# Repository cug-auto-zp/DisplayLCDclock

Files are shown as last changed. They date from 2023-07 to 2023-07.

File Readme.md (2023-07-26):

# Readme

[TOC]

## 0. 引言

之前一直想做一个辉光管时钟，由于成本太大，改为用LCD替换制作成类辉光管时钟，在github上看到了一个一模一样的项目废话不多说直接复刻

本项目为基于github上displayArray项目，其为一个开源的项目链接：[https://github.com/JosueAGtz/displayArray](https://github.com/JosueAGtz/displayArray)，项目作者使用的是==ESP32-S2==作为MCU，本人使用的是==合宙esp32-c3==，在复现的过程遇到了有几个问题之处。

- 遇到问题：
  
  - 图片显示都是反色。本人先买了==合宙esp32-c3（旧版）+LCD屏==测试了一下，这个LCD和项目使用的是一个屏幕都是ST7735s，一开始用转化好的图片.h库，显示是反色。本人重新取模发现这个屏幕是GBR排列，所以生成图片的时候得先反色再高位在前（为了方便本人已经将图片的.h重新更新了一下）
- 本人复刻过程
  - step1: 将==esp32-s2==代码转化可以烧录到合宙板子的代码，再用==合宙esp32-c3（旧版）+LCD屏==测试了一下程序，成功后就开始step2 设计PCB
  
    <video src="Readme-Fig/1.mp4"></video>
  
  - step2: 根据原理图重新设计并绘制PCB（ `主控` 和 `按键` 换了）
  
  - step3: 重新在别人的基础上更改及重新添加新功能
  
  - 注意：esp32-c3 的 GPIO11是需要解锁的，解锁前是一直给flash供电使用的，解锁后就可以当正常的GPIO使用。（在[Firmware](#3. Firmware)）

## SPI 屏幕——st7735

## 2. Hardware

主控：合宙esp32-c3开发版

官方手册链接：[ESP32C3-CORE开发板 - LuatOS 文档](https://wiki.luatos.com/chips/esp32c3/board.html)

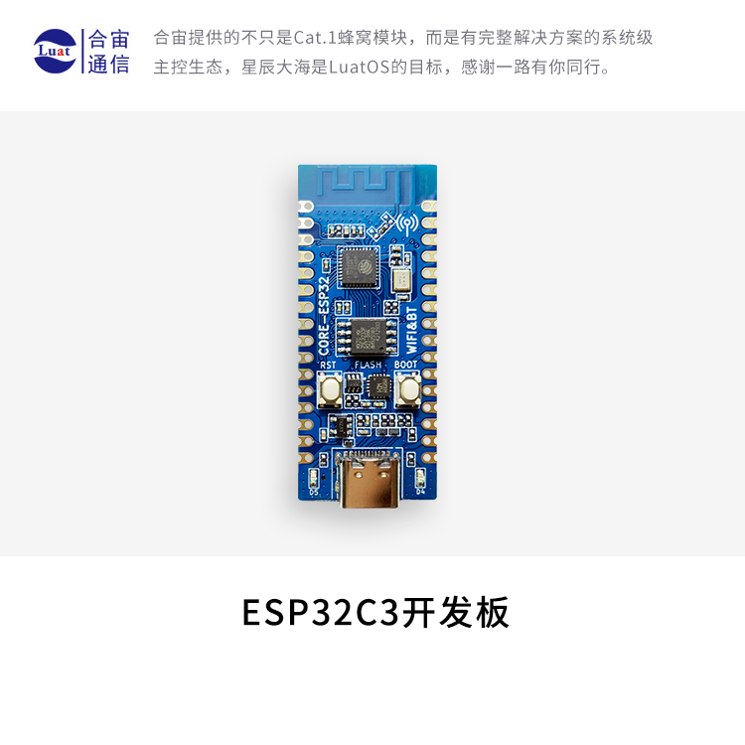
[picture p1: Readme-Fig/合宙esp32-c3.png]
合宙esp32-c3


其中使用AD20绘制了两个硬件

- displayLCD
- displaycontrl
- Hardware附件(材料来源等)

### 1. displayLCD

其中包含了6个SPI的TFT 80×160的屏幕的PCB，提供了5个按键可供多元创意开发

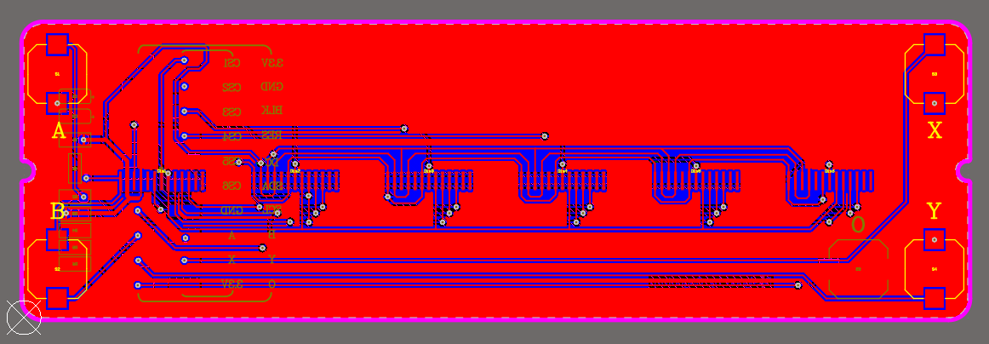
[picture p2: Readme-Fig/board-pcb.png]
board-pcb


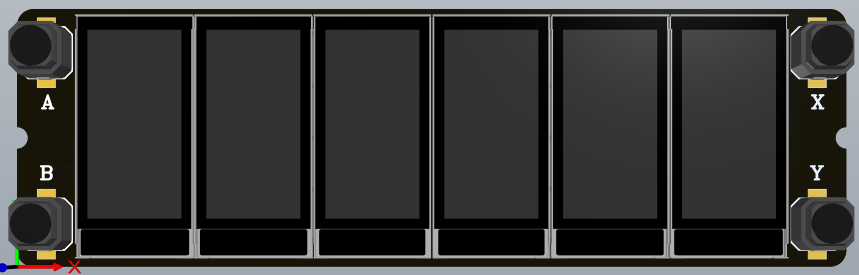
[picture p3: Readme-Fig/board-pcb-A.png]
board-pcb-A


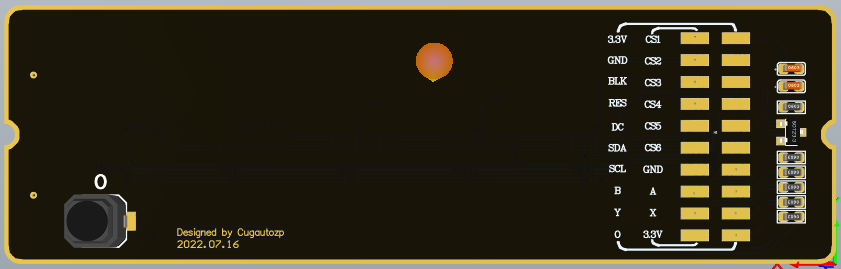
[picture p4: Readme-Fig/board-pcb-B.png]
board-pcb-B


实物如下：

### 2. displaycontrl

绘制了主控板，与合宙的esp32-c3开发板缝合。还留有 RX 和 TX 以供有人选取esp32-c3新版开发板下载程序问题。

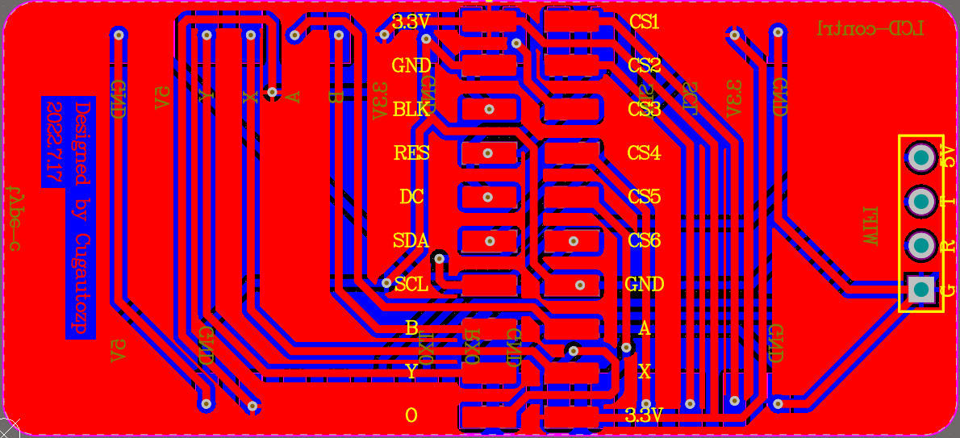
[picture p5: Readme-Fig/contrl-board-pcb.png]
contrl-board-pcb


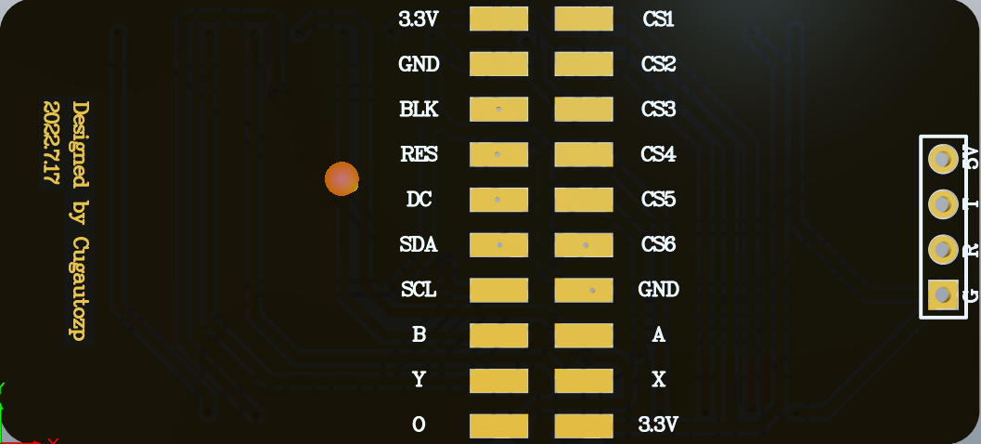
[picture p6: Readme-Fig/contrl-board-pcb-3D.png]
contrl-board-pcb-3D


实物图如下：

### 3. 硬件附件

| 材料 | 名称 | 购买链接 |
| :---: | :---: | :---: |
| TFT0.96”的屏幕 | st7735s (80×160) | |
| 开发板 | 合宙esp32-c3（旧版）价格：12.9，（新版）价格：9.9 | |
| 按键 | 6\*6*5贴片无声硅胶按键 | |
| 排针 | 卧式贴片排针公/母 | |

## 3. Firmware

采用编译环境是：Vscode + platformIO + Arduino框架

### 1. 安装教程

- Vscode 官方下载链接：[Visual Studio Code](https://code.visualstudio.com/)
- 看这位（up 主：Homepea）视频：[Vscode + platformIO + Arduino安装及配置环境教学视频](https://www.bilibili.com/video/BV1tv411w74d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)

### 2. 代码解释

- 代码在文件：`Firmware/code`
- 配置好环境后，打开工程文件`code`，编译一下主函数`main.cpp`
- 代码注意事项及部分解释在 [Code Readme](./Firmware/Readme.md) 

### 3. 图片取模Tool

- 为了增加diy可玩性，提供取模工具在文件`Tool`，以供大家选取自己喜欢的图片
- 如果图片是`.png`格式建议转化为`.jpg`格式

### 4. 二维码生成

- 二维的生成是用来配置esp32-c3的WiFi，让它连接想要连接的WiFi热点，比直接写在代码中会比较灵活一些

- Wifi 配置使用二维码扫描连接ESP32C3的热点(热点名及密码由 user_config.h 中 AP_SSID和AP_PASSWORD 配置), 同步需要修改二维码图片 (WifiQrcode.h): 

  ```txt
  WIFI:T:WPA;S:热点名;P:密码;
  
  例如：WIFI:T:WPA;S:esp32-c3;P:;
  ```

  到草料网：[草料二维码生成器 ](https://cli.im/) ，（可以更具自己的喜好更改样式）

  把上面的例子复制

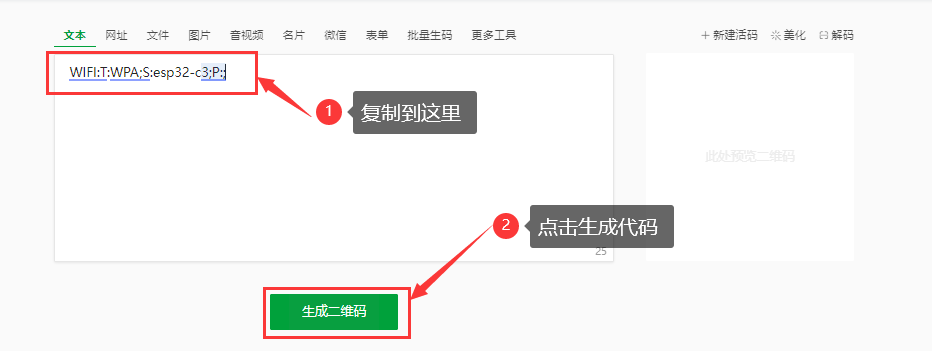
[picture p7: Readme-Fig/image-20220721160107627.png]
  

  点击这个设置，设置到 `80px`，改完后直接下载

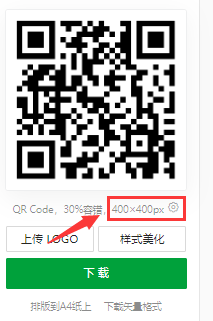
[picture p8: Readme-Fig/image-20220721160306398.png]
  

  > 在编写的过程中遇到了一些问题，询问了一位大佬，非常感谢这位大佬的答疑解惑，Github: [Kerrbty/ESP32C3Clock: 太空人时钟，基于ESP32-C3芯片](https://github.com/Kerrbty/ESP32C3Clock)

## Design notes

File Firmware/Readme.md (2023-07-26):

# Readme

## Code

### 1. 引脚配置

主控引脚定义：

引脚定义

上图预留给出了GPIO 0~13 和 18~19，下面进行本项目的功能复用，使用了一根SPI总线

`注意：`其中 GPIO 11 原来是给flash供电使用，所以需要解锁才能作为正常的 GPIO 使用，flash可以使用外部供电，不用担心解锁后存在的问题。解锁教程链接：[GPIO 11 解锁](https://gitee.com/dreamcmi/LuatOS-ESP32/blob/master/doc/VDD_SPI_AS_GPIO.md)

|  GPIO |  功能复用 | 说明 |
| :-----: | :---: | :---: |
| GPIO 0  | CS1 | 控制第一块LCD |
| GPIO 1  | CS2 | 控制第二块LCD |
| GPIO 2  | SCL（SCK）  | SPI的时钟 |
| GPIO 3  | MOSI（SDA） | |
| GPIO 4  | A | PCB-按键 A |
| GPIO 5  | B | PCB-按键 B |
| GPIO 6  | DC | |
| GPIO 7  | CS3 | 控制第三块LCD |
| GPIO 8  | X | PCB-按键 X |
| GPIO 9  | Y | PCB-按键 Y |
| GPIO 10 | RES | res复位 |
| GPIO 11 | BLK | 屏幕背光解锁后可以使用PWM调节背光 |
| GPIO 12 | CS4 | 控制第四块LCD |
| GPIO 13 | CS5 | 控制第五块LCD |
| GPIO 18 | CS6 | 控制第六块LCD |
| GPIO 19 | O | PCB-按键 O |
| | | |

### 2. code-v1.0

由于：Hardware 中 contrl-v1.0 板子有点小失误 GPIO18 控制第5块 LCD，GPIO13 控制第6块 LCD

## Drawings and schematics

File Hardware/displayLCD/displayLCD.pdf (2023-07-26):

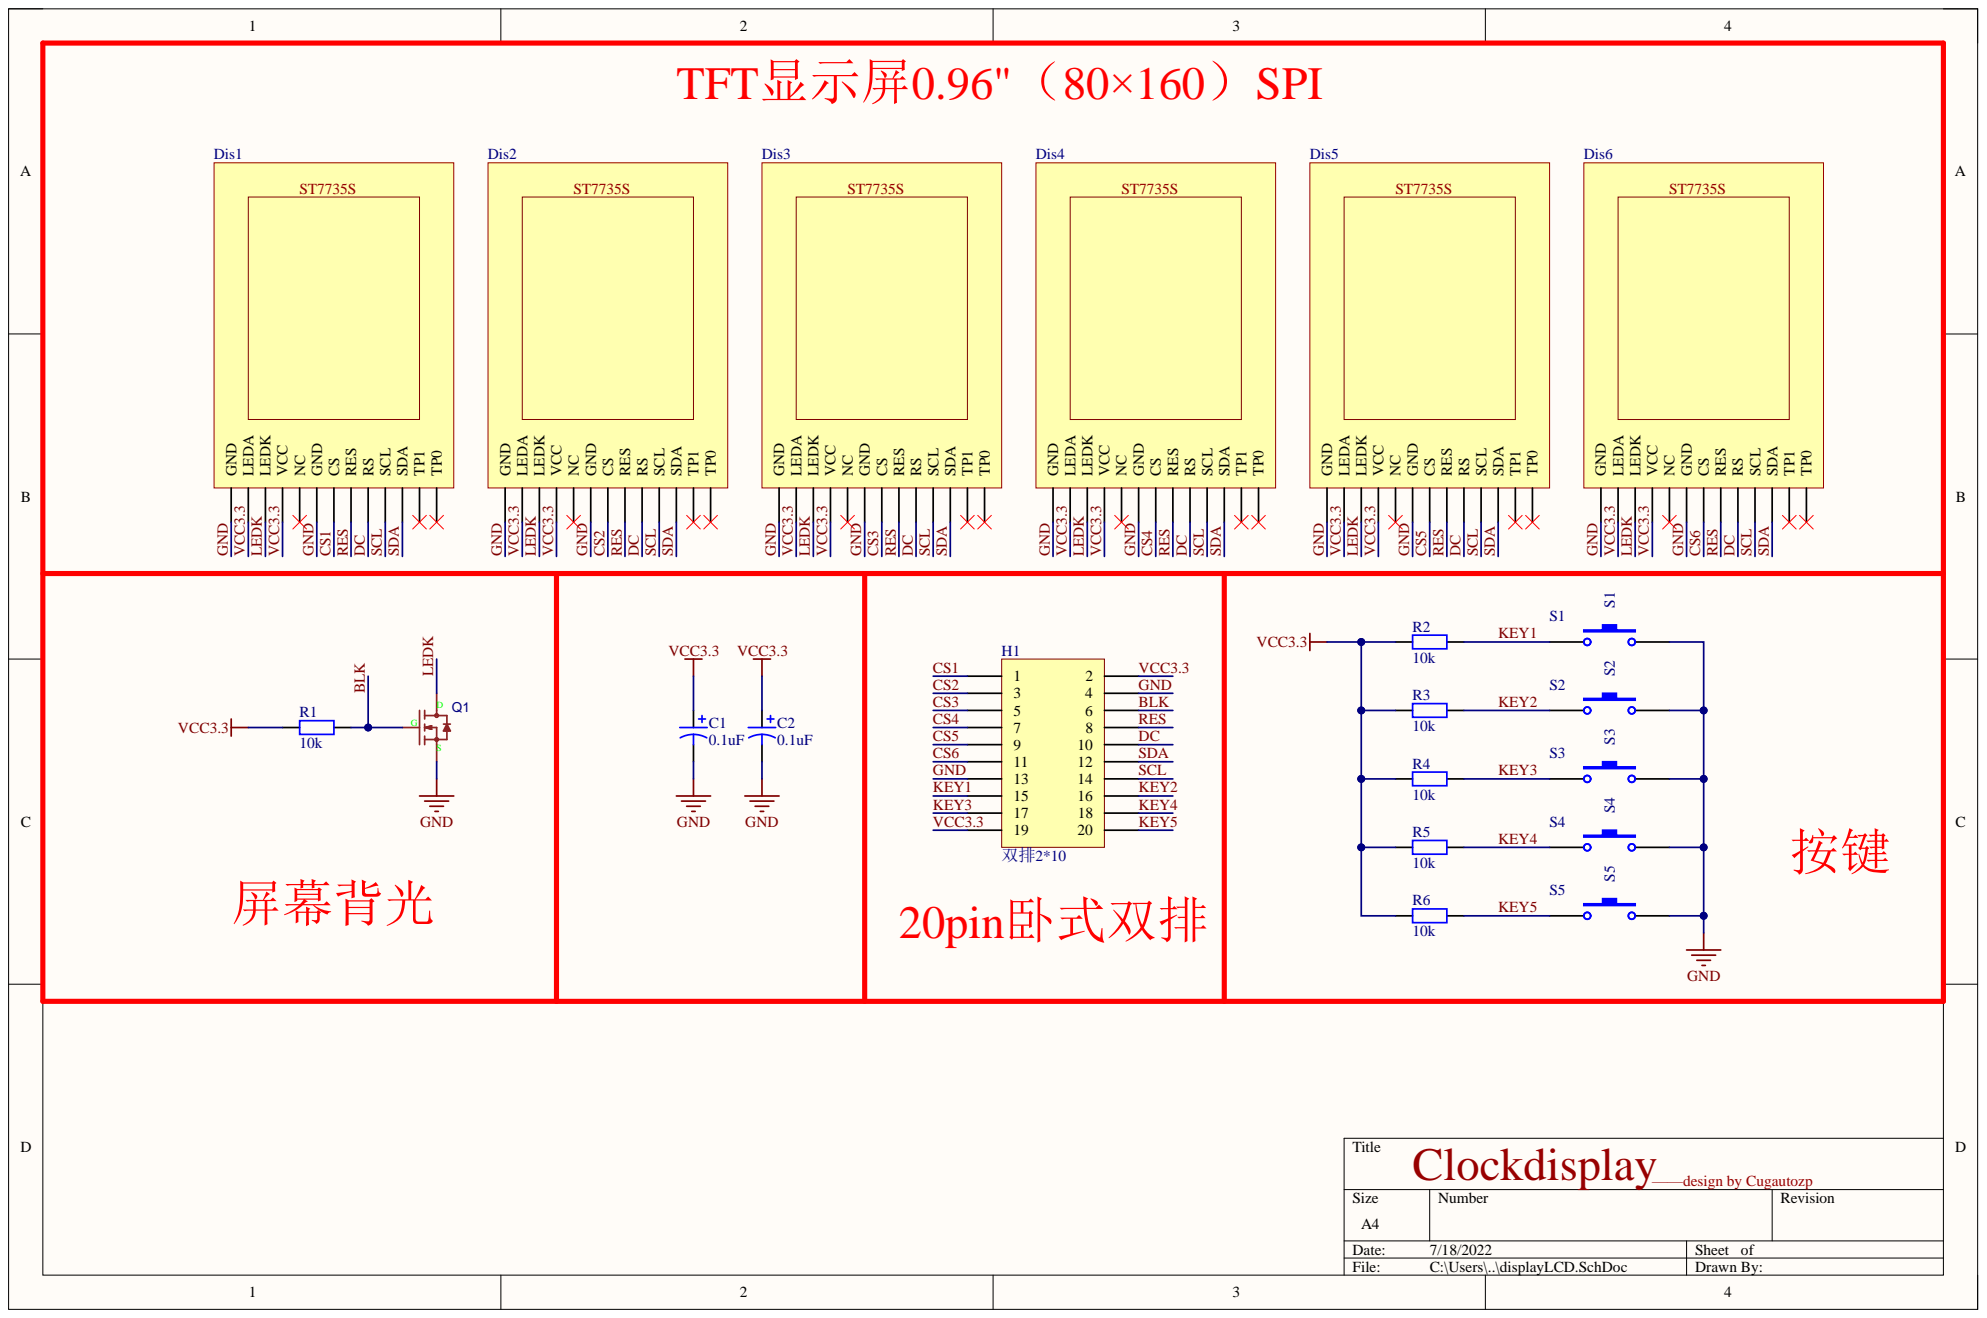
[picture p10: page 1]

Clockdisplay——design by Cugautozp

Item # | Designator | Description | Comment | Quantity #Column Name Error:' Manuf#Cacolture um n Name Error:' Manufacturer Part Num | Footprint | LibRef | #Column Name Error:' Note
1 | C1, C2 | Polarized Capacitor (Surface Mount) | 0.1uF | 2 | Cap0603 | Cap Pol3
2 | Dis1, Dis2, Dis3, Dis4, Dis5, Dis6 | | LCD80*160 | 6 | LCD屏80*160 | LCD80*160
3 | H1 | | 双排2*10 | 1 | pin20双排母 | 双排2*10
4 | Q1 | | LN4812LT1G | 1 | sot23 | LN4812LT1G
5 | R1, R2, R3, R4, R5, R6 | Resistor | 10k | 6 | R0603 | Res2
6 | S1 | Switch | S1 | 1 | key(按键) | SW-PB
7 | S2 | Switch | S2 | 1 | key(按键) | SW-PB
8 | S3 | Switch | S3 | 1 | key(按键) | SW-PB
9 | S4 | Switch | S4 | 1 | key(按键) | SW-PB
10 | S5 | Switch | S5 | 1 | key(按键) | SW-PB

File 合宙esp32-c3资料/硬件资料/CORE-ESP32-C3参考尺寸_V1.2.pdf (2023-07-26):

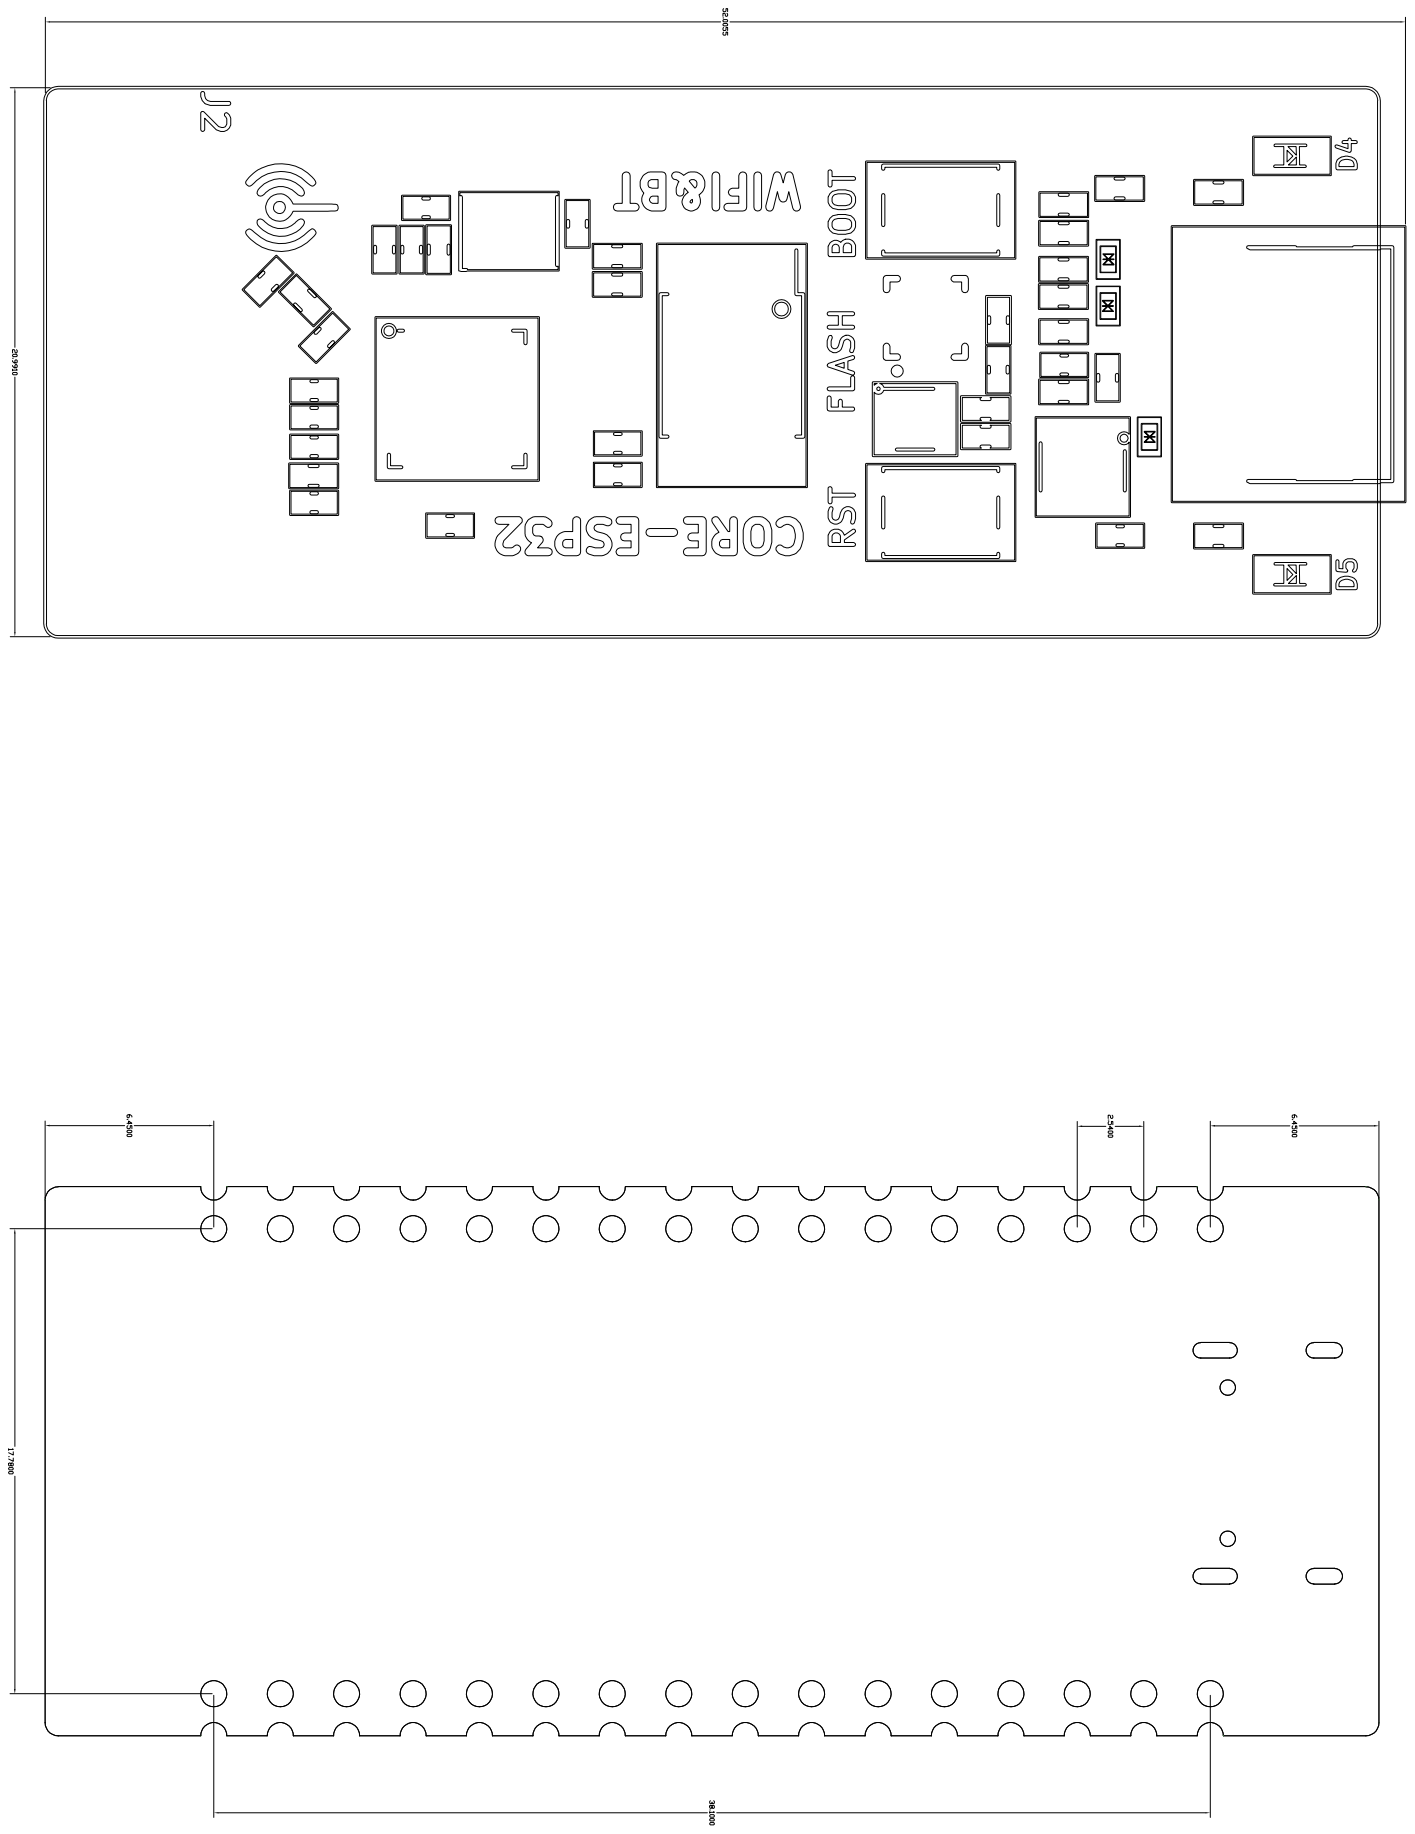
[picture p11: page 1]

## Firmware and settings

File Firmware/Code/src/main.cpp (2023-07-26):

#include "WiFiUser.h"     //  连接wifi热点选择配置网络
#include "displaystyle.h" //  展示样式

// //填写WIFI入网信息
// const char *ssid = "zp-laptop";     // WIFI账户
// const char *password = "cugautozp"; // WIFI密码

#define NTP1 "ntp1.aliyun.com"
#define NTP2 "ntp2.aliyun.com"
#define NTP3 "ntp3.aliyun.com"

// WiFiUDP ntpUDP;
// NTPClient timeClient(ntpUDP,"ntp.ntsc.ac.cn");

#define Key0 4  //  A
#define Key1 5  //  B
#define Key2 8  // x
#define Key3 9  // y
#define Key4 19 // o 暂时没有使用

// ST7735 width height
#define DISPLAY_WIDTH 160
#define DISPLAY_HEIGHT 80

int64_t stylenum = 1;
int64_t stylenum1 = 1;

uint8_t secondsCounter = 0;
uint8_t secondsStatus = 0;
uint8_t prevHours, prevMinutes;
struct tm timeinfo;

uint8_t b = 0;

int64_t blkpwm = 512; // 背光初始状态
int64_t blkpwm1 = 0;  // 保存当前背光状态
int64_t blkpwm2 = 0;  // 附状态机状态
int64_t keyFlag = 0;  // 按键状态
int64_t keyFlag1 = 0; // 按键状态

void setClock()
{
  if (!getLocalTime(&timeinfo))
  { //如果获取失败，就开启联网模式，获取时间
    Serial.println("Failed to obtain time");

    /*
       WIFI 直接连接
    */
    // WiFi.disconnect(false);
    // WiFi.mode(WIFI_STA); //开启网络
    // WiFi.begin(ssid, password);
    // while (WiFi.status() != WL_CONNECTED)
    // {
    //   delay(500);
    //   Serial.print(".");
    // }

    // 读取之前的wifi配置
    if (!ReadWifiConfig())
    {
      ConfigWifi();
    }

    // 连接wifi
    while (!ConnectWifi())
    {
      ConfigWifi();
    }
    spilcdWriteString(&lcd[5], 0, 0, (char *)"WIFI ok!", 0xffff, 0x0000, FONT_8x8, DRAW_TO_LCD);

    configTime(8 * 3600, 0, NTP1, NTP2, NTP3);
    return;
  }
  // Serial.println(&timeinfo, "%F %T %A"); // 格式化输出:2021-10-24 23:00:44 Sunday
  // Serial.println(timeinfo.tm_hour);
  WiFi.disconnect(true);
}

void LCD_init()
{

  ledcWrite(1, 0);
  pinMode(RESET_PIN, OUTPUT);
  digitalWrite(RESET_PIN, HIGH);
  digitalWrite(RESET_PIN, LOW);
  delay(50);
  digitalWrite(RESET_PIN, HIGH);

  for (int i = 0; i < 6; i++)
  {
    spilcdInit(&lcd[i], LCD_ST7735S_B, FLAGS_INVERT | FLAGS_SWAP_RB, 40000000, cs[i], DC_PIN, -1, -1, MISO_PIN, MOSI_PIN, SCK_PIN);
    spilcdSetOrientation(&lcd[i], LCD_ORIENTATION_180);
    lcdDrawNumber(i, 11, stylenum);
  }
  ledcWrite(1, blkpwm);
}

// void wifi_init()
// {
//   uint8_t wifiConectionAttmps = 0;
//   WiFi.mode(WIFI_STA); // wifi 连接模式
//   WiFi.begin(ssid, password);

//   Serial.print("Connecting to ");
//   Serial.print(ssid);
//   while (WiFi.status() != WL_CONNECTED & wifiConectionAttmps < 20)
//   {
//     delay(500);
//     Serial.print(".");
//     wifiConectionAttmps++;
//   }

//   if (WiFi.status() == WL_CONNECTED)
//   {
//     Serial.println("OK. WiFi connected!");
//   }
//   else
//   {
//     Serial.println("ERROR.");
//     Serial.println("Connection Failed!, please check credentials and try again.");
//   }
// }

void gethour(uint8_t stylenum)
{
  if (timeinfo.tm_hour != prevHours | stylenum1 != stylenum)
  {
    prevHours = timeinfo.tm_hour;
    // Serial.println(timeinfo.tm_hour);
    if (timeinfo.tm_hour < 10)
    {
      lcdDrawNumber(0, 0, stylenum);
      lcdDrawNumber(1, timeinfo.tm_hour, stylenum);
    }
    else if (timeinfo.tm_hour < 20)
    {
      lcdDrawNumber(0, 1, stylenum);
      lcdDrawNumber(1, timeinfo.tm_hour - 10, stylenum);
    }
    else
    {
      lcdDrawNumber(0, 2, stylenum);
      lcdDrawNumber(1, timeinfo.tm_hour - 20, stylenum);
    }
  }
}

void getmin(uint8_t stylenum)
{
  if (timeinfo.tm_min != prevMinutes | stylenum1 != stylenum)
  {
    prevMinutes = timeinfo.tm_min;
    // Serial.println(timeinfo.tm_min);
    if (timeinfo.tm_min < 10)
    {
      lcdDrawNumber(3, 0, stylenum);
      lcdDrawNumber(4, timeinfo.tm_min, stylenum);
    }
    else if (timeinfo.tm_min < 20)
    {
      lcdDrawNumber(3, 1, stylenum);
      lcdDrawNumber(4, timeinfo.tm_min - 10, stylenum);
    }
    else if (timeinfo.tm_min < 30)
    {
      lcdDrawNumber(3, 2, stylenum);
      lcdDrawNumber(4, timeinfo.tm_min - 20, stylenum);
    }
    else if (timeinfo.tm_min < 40)
    {
      lcdDrawNumber(3, 3, stylenum);
      lcdDrawNumber(4, timeinfo.tm_min - 30, stylenum);
    }
    else if (timeinfo.tm_min < 50)
    {
      lcdDrawNumber(3, 4, stylenum);
      lcdDrawNumber(4, timeinfo.tm_min - 40, stylenum);
    }
    else
    {
      lcdDrawNumber(3, 5, stylenum);
      lcdDrawNumber(4, timeinfo.tm_min - 50, stylenum);
    }
  }
}

void getmin1(uint8_t stylenum)
{
  if (timeinfo.tm_min != prevMinutes | stylenum1 != stylenum)
  {
    prevMinutes = timeinfo.tm_min;
    // Serial.println(timeinfo.tm_min);
    if (timeinfo.tm_min < 10)
    {
      lcdDrawNumber(2, 0, stylenum);
      lcdDrawNumber(3, timeinfo.tm_min, stylenum);
    }
    else if (timeinfo.tm_min < 20)
    {
      lcdDrawNumber(2, 1, stylenum);
      lcdDrawNumber(3, timeinfo.tm_min - 10, stylenum);
    }
    else if (timeinfo.tm_min < 30)
    {
      lcdDrawNumber(2, 2, stylenum);
      lcdDrawNumber(3, timeinfo.tm_min - 20, stylenum);
    }
    else if (timeinfo.tm_min < 40)
    {
      lcdDrawNumber(2, 3, stylenum);
      lcdDrawNumber(3, timeinfo.tm_min - 30, stylenum);
    }
    else if (timeinfo.tm_min < 50)
    {
      lcdDrawNumber(2, 4, stylenum);
      lcdDrawNumber(3, timeinfo.tm_min - 40, stylenum);
    }
    else
    {
      lcdDrawNumber(2, 5, stylenum);
      lcdDrawNumber(3, timeinfo.tm_min - 50, stylenum);
    }
  }
}

void getsec(uint8_t stylenum)
{
  if (timeinfo.tm_sec != prevMinutes | stylenum1 != stylenum)
  {
    prevMinutes = timeinfo.tm_sec;
    Serial.println(timeinfo.tm_sec);
    if (timeinfo.tm_sec < 10)
    {
      lcdDrawNumber(4, 0, stylenum);
      lcdDrawNumber(5, timeinfo.tm_sec, stylenum);
    }
    else if (timeinfo.tm_sec < 20)
    {
      lcdDrawNumber(4, 1, stylenum);
      lcdDrawNumber(5, timeinfo.tm_sec - 10, stylenum);
    }
    else if (timeinfo.tm_sec < 30)
    {
      lcdDrawNumber(4, 2, stylenum);
      lcdDrawNumber(5, timeinfo.tm_sec - 20, stylenum);
    }
    else if (timeinfo.tm_sec < 40)
    {
      lcdDrawNumber(4, 3, stylenum);
      lcdDrawNumber(5, timeinfo.tm_sec - 30, stylenum);
    }
    else if (timeinfo.tm_sec < 50)
    {
      lcdDrawNumber(4, 4, stylenum);
      lcdDrawNumber(5, timeinfo.tm_sec - 40, stylenum);
    }
    else
    {
      lcdDrawNumber(4, 5, stylenum);
      lcdDrawNumber(5, timeinfo.tm_sec - 50, stylenum);
    }
  }
}

void clkcolon(uint8_t stylenum )
{

  // if 
 
  if ((stylenum1 != stylenum) | (secondsCounter > 25 & secondsStatus == 0) )
  {
    lcdDrawNumber(2, 10, stylenum);
    // lcdDrawNumber(6,10);
    secondsStatus = 1;
    secondsCounter = 0;
  }
  else if (  (secondsCounter > 25 & secondsStatus == 1) | (stylenum1 != stylenum))
  {
    lcdDrawNumber(2, 11, stylenum);
    // lcdDrawNumber(6,11);
    secondsStatus = 0;
    secondsCounter = 0;
  }

  delay(20);
  secondsCounter++;

  // if (stylenum1 != stylenum)
  // {
  //   secondsCounter = 0;
  //   secondsStatus = 0;
  // }


}

// void KeyScan()
// {

//   if (keyFlag == 1)
//   {
//     // 检查按键是否释放
//     if (digitalRead(Key0) == 0)
//       return;
//     else if (digitalRead(Key1) == 0)
//       return;
//     else if (digitalRead(Key2) == 0)
//       return;
//     else if (digitalRead(Key3) == 0)
//       return;
//     else if (digitalRead(Key4) == 0)
//       return;
//     else
//       keyFlag = 0; //按键已经释放
//   }

//   else
//   {
//     if (digitalRead(Key0) == 0)
//     {
//       keyFlag = 1;
//       stateFlag = stateFlag + 20;
//       if (stateFlag > 1024)
//         stateFlag = 0;
//       return;
//     }
//     else if (digitalRead(Key1) == 0)
//     {
//       keyFlag = 1;
//       if (stateFlag > 0)
//         stateFlag = stateFlag - 20;
//       else
//         stateFlag = 1024;
//       return;
//     }
//     else if (digitalRead(Key2) == 0)
//     {
//       keyFlag = 1;
//       if (b == 0)
//         b = 1;
//       else
//         b = 0;

//       return;
//     }
//     else if (digitalRead(Key3) == 0)
//     {
//       keyFlag = 1;

//       stateFlag2 = stateFlag2 + 1;
//       if (stateFlag2 > 2)
//         stateFlag2 = 0;
//       return;
//     }
//     else if (digitalRead(Key4) == 0)
//     {
//       keyFlag = 1;

//       if (stateFlag > 0)
//       {
//         a = stateFlag;
//         stateFlag = 0;
//       }
//       else
//         stateFlag = a;
//       return;

//       if (stateFlag > 0)
//       {
//         a = stateFlag;
//         stateFlag = 0;
//       }
//       else
//         stateFlag = a;
//       return;
//     }
//   }
// }

void KeyScan()
{

  if (keyFlag == 0)
  {
    // 检查按键是否释放
    if (digitalRead(Key0) == 0)
    {

      spilcdWriteString(&lcd[5], 0, 40, (char *)"Seting", 0xffff, 0x0000, FONT_8x8, DRAW_TO_LCD);
      keyFlag = 1;
      return;
    }
    else if (digitalRead(Key1) == 0)
      return;
    else if (digitalRead(Key2) == 0)
      return;
    else if (digitalRead(Key3) == 0)
      return;
    else if (digitalRead(Key4) == 0)
      return;
    else
      keyFlag = 0; //按键已经释放
  }
  else if (keyFlag == 1)
  {
    if (keyFlag1 == 1)
    {
      if (digitalRead(Key0) == 0)
        return;
      else if (digitalRead(Key1) == 0)
        return;
      else if (digitalRead(Key2) == 0)
        return;
      else if (digitalRead(Key3) == 0)
        return;
      else if (digitalRead(Key4) == 0)
        return;
      else
        keyFlag1 = 0; //按键已经释放
    }
    else if (keyFlag1 == 0)
    {
      if (digitalRead(Key0) == 0)
      {
        keyFlag1 = 1;
        blkpwm = blkpwm + 20;
        if (blkpwm > 1024)
          blkpwm = 0;
        return;
      }
      else if (digitalRead(Key1) == 0)
      {
        keyFlag1 = 1;
        if (blkpwm > 0)
          blkpwm = blkpwm - 20;
        else
          blkpwm = 1024;
        return;
      }
      else if (digitalRead(Key2) == 0)
      {
        keyFlag1 = 1; 
        stylenum1 =stylenum;
        stylenum = stylenum + 1;
        
        if (stylenum > 8) 
          stylenum = 0;
        return;
      }
      else if (digitalRead(Key3) == 0)
      {
        keyFlag1 = 1;
        stylenum1 =stylenum;
        stylenum = stylenum - 1;
        if (stylenum < 0)       
          stylenum = 8;
        return;
      }
      else if (digitalRead(Key4) == 0)
      {
        keyFlag1 = 1;

        if (blkpwm > 0)
        {
          blkpwm1 = blkpwm;
          blkpwm = 0;
        }
        else
          blkpwm = blkpwm1;
        return;
      }
    }
  }
}

void setup()
{
  Serial.begin(115200);
  while (!Serial)
    ;
  pinMode(11, OUTPUT);
  ledcSetup(1, 1000, 10);
  ledcAttachPin(11, 1);
  ledcWrite(1, blkpwm);

  pinMode(Key0, INPUT_PULLUP);
  pinMode(Key1, INPUT_PULLUP);
  pinMode(Key2, INPUT_PULLUP);
  pinMode(Key3, INPUT_PULLUP);
  pinMode(Key4, INPUT_PULLUP);

  LCD_init(); // 屏幕初始化

  // lcdDrawFlag(5, 3); //

  // wifi_init();                               // wifi初始化
  configTime(8 * 3600, 0, NTP1, NTP2, NTP3); // 时区设定 北京时间为 GTM +8
  setClock();
  // 读取之前的wifi配置
    if ( !ReadWifiConfig() )
    {
        ConfigWifi();
    }

    // 连接wifi
    while( !ConnectWifi() )
    {
        ConfigWifi();
    }

  WiFi.disconnect(true);
  WiFi.mode(WIFI_OFF); //关闭网络

  // Serial.println("WiFi disconnected!");
  // timeClient.begin();
  // timeClient.setTimeOffset(8*3600);     // 时区设定 北京时间为 GTM +8
  // timeClient.update();

  prevHours = 60;
  prevMinutes = 60;
}

void loop()
{

  Serial.println(stylenum);
  // Serial.println("up: ");
  KeyScan();
  ledcWrite(1, blkpwm);
  // Serial.print(blkpwm);
  setClock();

  switch (b)
  {
  case 0:
    gethour(stylenum);
    getmin(stylenum);
    clkcolon(stylenum);
    lcdDrawNumber(5, 12, stylenum);
    stylenum1 = stylenum;
    Serial.println(stylenum1);
    break;

  case 1:
    gethour(stylenum);

    // getmin();

    getmin1(stylenum);
    //
    getsec(stylenum);
    break;
  }
}

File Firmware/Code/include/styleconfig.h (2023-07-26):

#ifndef __STYLECONFIG_H__
#define __STYLECONFIG_H__

// #include "clock14SEG.h"
#include "clockBINA.h"
#include "clockButterfly.h"
#include "clockDigital.h"
#include "clockFlip.h"
#include "clockFlower.h"
#include "clockInk.h"
#include "clockLixieCyan.h"
#include "clockLixiePurple.h"
#include "clockMatrix.h"
// #include "clockNIMO.h"
#include "clockNixie.h"
#include "clockPixie.h"
#include "clockPredator.h"
#include "clockRGB.h"
#include "clockStargate.h"
#include "clockVFD.h"
// #include "clockWood.h"
// #include "clockFlags.h"

/*   屏幕引脚配置   */

#define CS1_PIN 0  // 1
#define CS2_PIN 1  // 18 //2
#define CS3_PIN 7  // 13//5 //3
#define CS4_PIN 12 // 4
#define CS5_PIN 18 // 19
#define CS6_PIN 13 // 7 //6

#define RESET_PIN 10    //    res
#define DC_PIN    6     //    DC
#define MOSI_PIN  3     //    SDA
#define SCK_PIN   2     //    SCL
#define LED_PIN   11    //    BLK   LCD背光
#define MISO_PIN -1     //    引脚为空


#define colon  10
#define space  11
#define heart  12
    



/*   style切换   */
// #define SEG14           0
#define BINA            0 // 1 
#define Butterfly       1 // 2
// #define Digital         3
#define Flip            2 // 4 
#define Flower          3 // 5
#define Ink             4 // 6
// #define LixieCyan       7
#define LixiePurple     5 // 8
// #define Matrix          9
// #define NIMO            10
#define Nixie           6 // 11
// #define Pixie           12
// #define Predator        13
#define RGB             7 // 14
// #define Stargate        15
#define VFD             8 // 16
// #define Wood            17
// #define Flags           18


#endif

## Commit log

2023-07-26 第一次开源上传
    [PCB_Project.PrjPcb, contrl.PcbDoc, contrl.PcbLib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]
2023-07-26 第一次开源
